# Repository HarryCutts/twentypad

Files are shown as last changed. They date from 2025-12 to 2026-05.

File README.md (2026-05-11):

# TwentyPad
TwentyPad is a simple twenty-key macro pad, that I built to learn about PCB design.

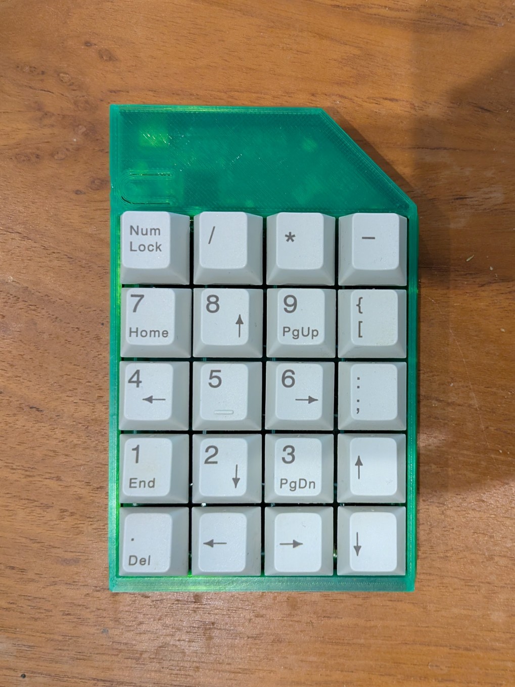
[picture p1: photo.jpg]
Photo of TwentyPad in its 3D-printed case


This repository contains the KiCAD project for PCB manufacture and assembly. The case was [designed
in Onshape][onshape-proj].

[onshape-proj]: https://cad.onshape.com/documents/e1701c21a3cb18f7b5686e27/w/70a0bcde95206762f85e44bf/e/dfee6d06467dfd7de2e80397

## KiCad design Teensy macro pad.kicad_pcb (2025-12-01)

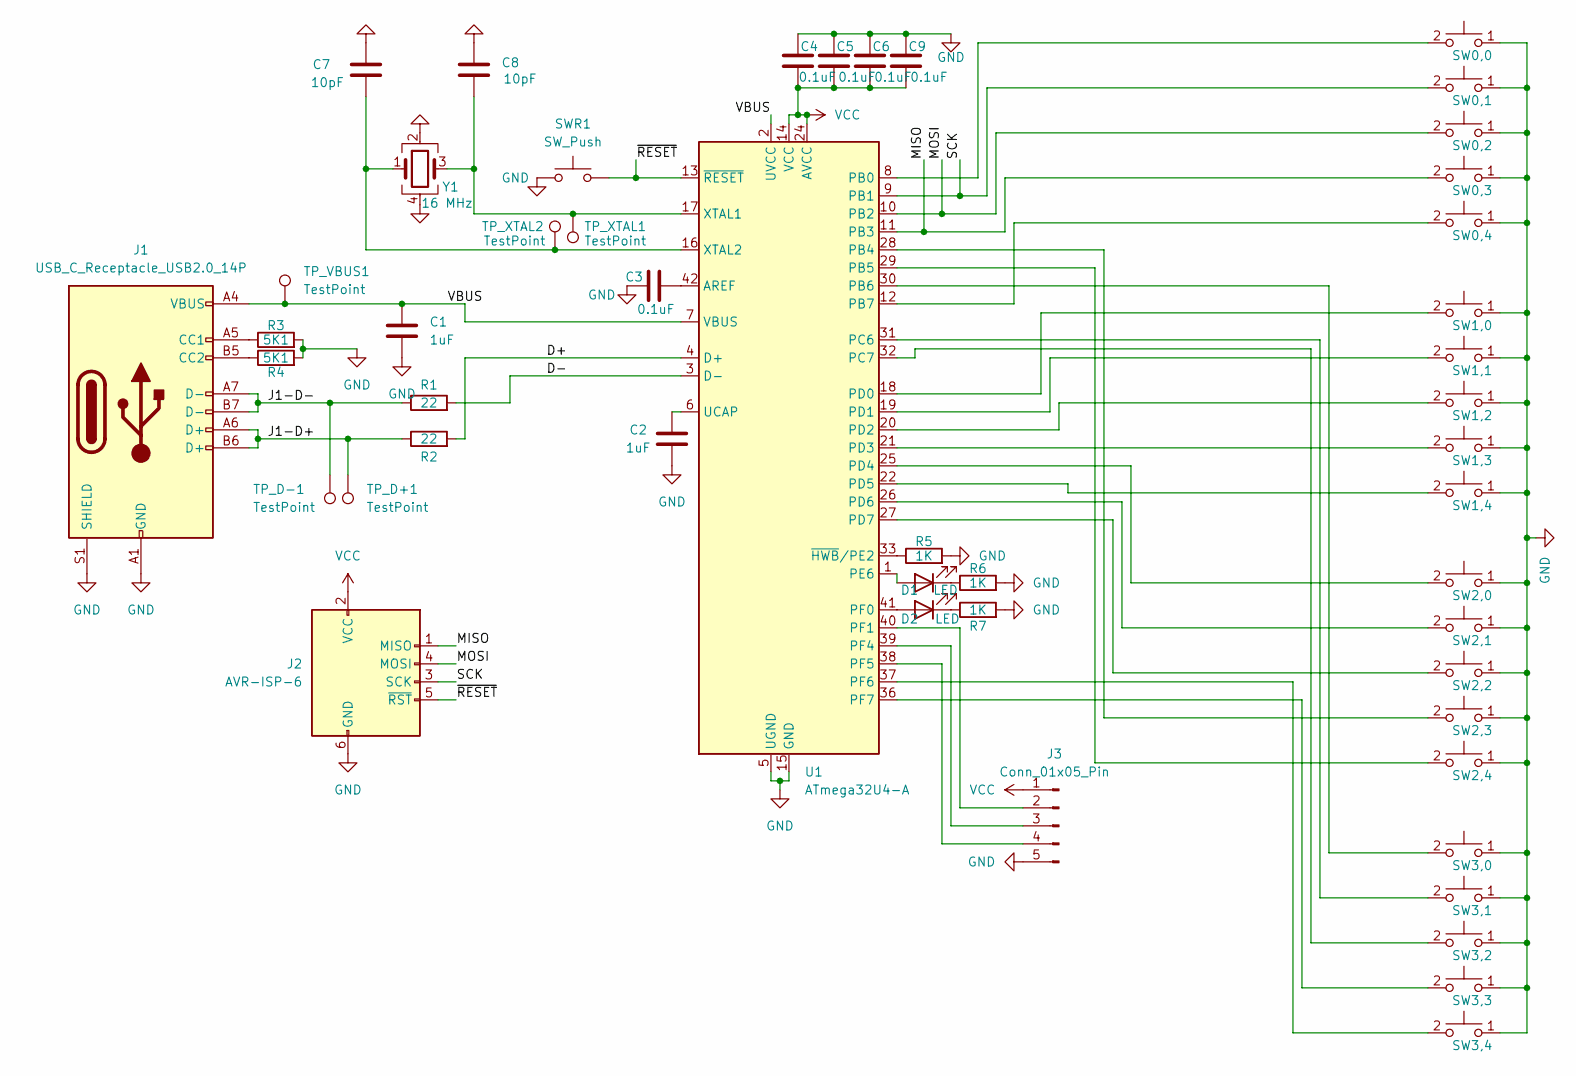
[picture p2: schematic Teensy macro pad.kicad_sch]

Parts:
C1, C2: 1uF; C_0805_2012Metric
C3, C4, C5, C6, C9: 0.1uF; C_0805_2012Metric
C7, C8: 10pF; C_0603_1608Metric
D1, D2: LED; LED_D5.0mm
J1: USB_C_Receptacle_USB2.0_14P; USB_C_Receptacle_HRO_TYPE-C-31-M-12
J2: AVR-ISP-6; IDC-Header_2x03_P2.54mm_Vertical
J3: Conn_01x05_Pin; PinHeader_1x05_P2.54mm_Vertical
R1, R2: 22; R_0805_2012Metric
R3, R4: 5K1; R_0805_2012Metric
R5, R6, R7: 1K; R_0805_2012Metric
SW0,0, SW0,1, SW0,2, SW0,3, SW0,4, SW1,0, SW1,1, SW1,2, SW1,3, SW1,4, SW2,0, SW2,1, SW2,2, SW2,3, SW2,4, SW3,0, SW3,1, SW3,2, SW3,3, SW3,4: CherryMX; SW_Cherry_MX_1.00u_PCB_with_bridge
SWR1: SW_Push; SW_Push_1P1T_XKB_TS-1187A
TP_D+1: TestPoint; TestPoint_Pad_D2.0mm
TP_D-1: TestPoint; TestPoint_Pad_D2.0mm
TP_VBUS1: TestPoint; TestPoint_Pad_D2.0mm
TP_XTAL1, TP_XTAL2: TestPoint; TestPoint_Pad_D2.0mm
U1: ATmega32U4-A; TQFP-44_10x10mm_P0.8mm
Y1: 16 MHz; Crystal_SMD_3225-4Pin_3.2x2.5mm

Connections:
/D+: R2.2, U1.4 (D+)
/D-: R1.2, U1.3 (D-)
/J1-D+: J1.A6 (D+), J1.B6 (D+), R2.1, TP_D+1.1
/J1-D-: J1.A7 (D-), J1.B7 (D-), R1.1, TP_D-1.1
/MISO: J2.1 (MISO), SW0,3.2, U1.11 (PB3)
/MOSI: J2.4 (MOSI), SW0,2.2, U1.10 (PB2)
/SCK: J2.3 (SCK), SW0,1.2, U1.9 (PB1)
/VBUS: C1.1, J1.A4 (VBUS), J1.A9 (VBUS), J1.B4 (VBUS), J1.B9 (VBUS), TP_VBUS1.1, U1.2 (UVCC), U1.7 (VBUS)
/~RESET: J2.5 (~RST), SWR1.2, U1.13 (~RESET)
GND: C1.2, C2.2, C3.1, C4.2, C5.2, C6.2, C7.1, C8.1, C9.2, J1.A1 (GND), J1.A12 (GND), J1.B1 (GND), J1.B12 (GND), J1.S1 (SHIELD), J2.6 (GND), J3.5, R3.2, R4.2, R5.2, R6.2, R7.2, SW0,0.1, SW0,1.1, SW0,2.1, SW0,3.1, SW0,4.1, SW1,0.1, SW1,1.1, SW1,2.1, SW1,3.1, SW1,4.1, SW2,0.1, SW2,1.1, SW2,2.1, SW2,3.1, SW2,4.1, SW3,0.1, SW3,1.1, SW3,2.1, SW3,3.1, SW3,4.1, SWR1.1, U1.5 (UGND), U1.15 (GND), U1.23 (GND), U1.35 (GND), U1.43 (GND), Y1.2, Y1.4
unnamed: D1.2 (A), U1.1 (PE6)
unnamed: D1.1 (K), R6.1
unnamed: D2.2 (A), U1.41 (PF0)
unnamed: D2.1 (K), R7.1
unnamed: J1.A5 (CC1), R3.1
unnamed: J1.B5 (CC2), R4.1
unnamed: J3.2, U1.40 (PF1)
unnamed: J3.3, U1.39 (PF4)
unnamed: J3.4, U1.38 (PF5)
unnamed: C3.2, U1.42 (AREF)
unnamed: SW0,0.2, U1.8 (PB0)
unnamed: SW2,3.2, U1.28 (PB4)
unnamed: SW2,4.2, U1.29 (PB5)
unnamed: SW3,0.2, U1.30 (PB6)
unnamed: SW0,4.2, U1.12 (PB7)
unnamed: SW3,1.2, U1.31 (PC6)
unnamed: SW3,2.2, U1.32 (PC7)
unnamed: SW1,0.2, U1.18 (PD0)
unnamed: SW1,1.2, U1.19 (PD1)
unnamed: SW1,2.2, U1.20 (PD2)
unnamed: SW1,3.2, U1.21 (PD3)
unnamed: SW2,0.2, U1.25 (PD4)
unnamed: SW1,4.2, U1.22 (PD5)
unnamed: SW2,1.2, U1.26 (PD6)
unnamed: SW2,2.2, U1.27 (PD7)
unnamed: SW3,4.2, U1.37 (PF6)
unnamed: SW3,3.2, U1.36 (PF7)
unnamed: C2.1, U1.6 (UCAP)
unnamed: C8.2, TP_XTAL1.1, U1.17 (XTAL1), Y1.3
unnamed: C7.2, TP_XTAL2.1, U1.16 (XTAL2), Y1.1
unnamed: R5.1, U1.33 (~HWB/PE2)
VCC: C4.1, C5.1, C6.1, C9.1, J2.2 (VCC), J3.1, U1.14 (VCC), U1.24 (AVCC), U1.34 (VCC), U1.44 (AVCC)

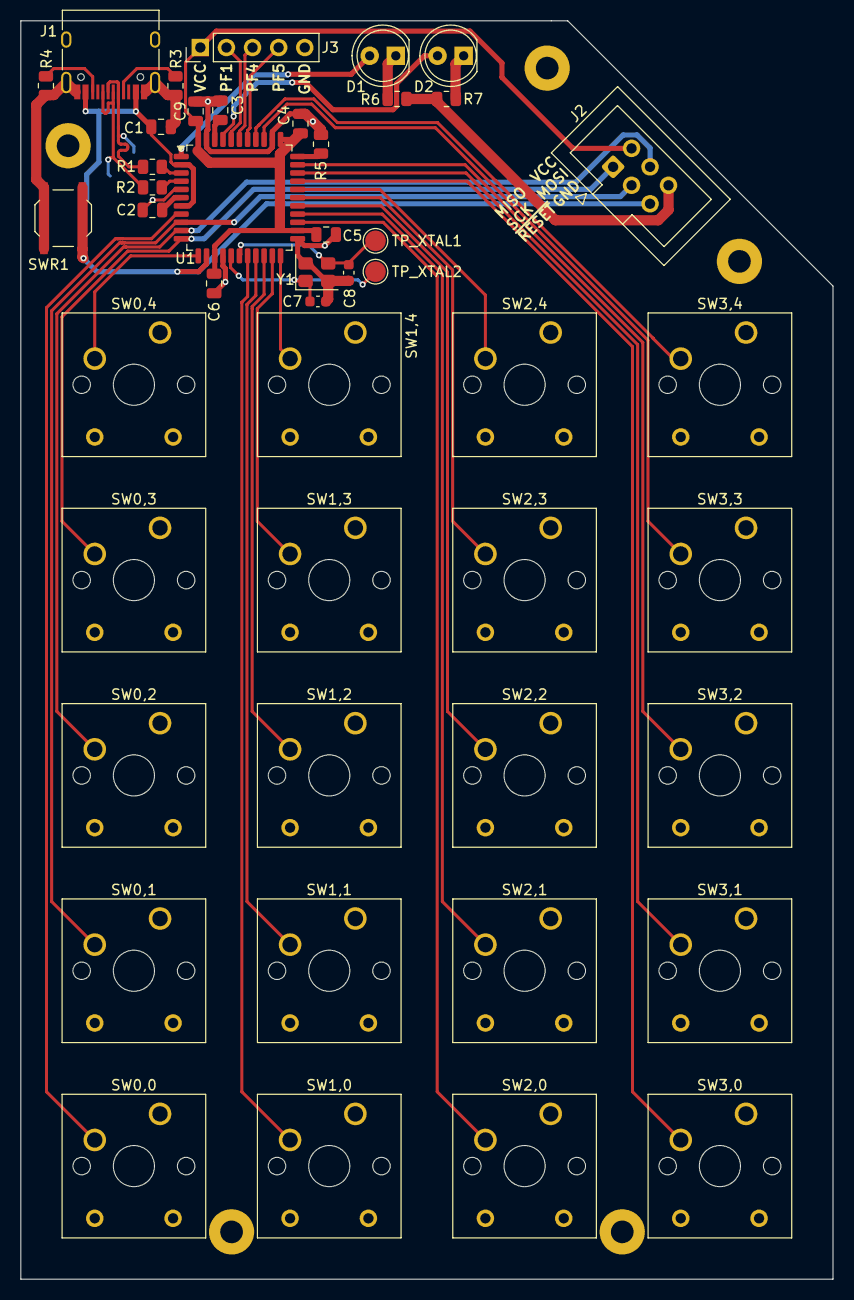
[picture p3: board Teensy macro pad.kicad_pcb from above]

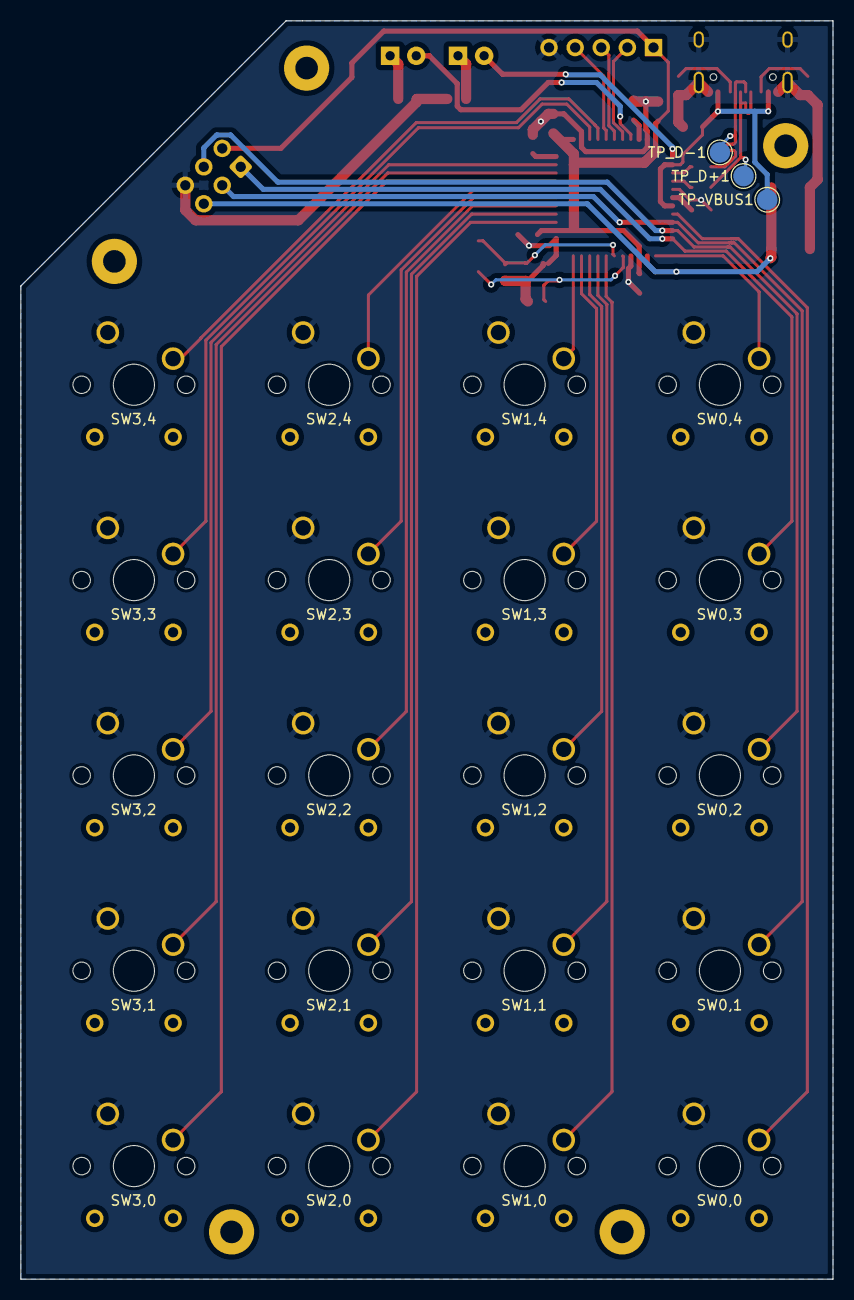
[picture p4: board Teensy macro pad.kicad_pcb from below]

Board: 2 copper layers, 79.0 x 122.4 mm, 54 parts (3 on the bottom side), 42 nets.

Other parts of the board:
HOLE1, HOLE2, HOLE3, HOLE4, HOLE5: MountingHole_2.2mm_M2_Pad

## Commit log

2025-06-28 Add partially-complete design with Teensy 2.0
    [Teensy macro pad.kicad_pcb, Teensy macro pad.kicad_sch]
2025-07-05 Switch to putting the chip on the board directly
    [Teensy macro pad.kicad_pcb, Teensy macro pad.kicad_sch]
2025-07-05 Load in JLCPCB capabilities and fix some violations
    I loaded the constraints from https://jlcpcb.com/capabilities/ into the
    board setup, then ran the DRC and fixed some of the issues (not all,
    since I need to do some re-arrangement anyway).
    [Teensy macro pad.kicad_pcb]
2025-07-06 Move decoupling capacitors to be one per VCC pin
    Pages 5 and 6 of AN2519 [0] are particularly relevant here.
    [0]: https://ww1.microchip.com/downloads/aemDocuments/documents/MCU08/ApplicationNotes/ApplicationNotes/AN2519-AVR-Microcontroller-Hardware-Design-Considerations-00002519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
    [Teensy macro pad.kicad_pcb, Teensy macro pad.kicad_sch]
2025-07-06 Add a decoupling capacitor to VCC pin 44
    This isn't on the Teensy, but AN2519 is quite clear that "For devices
    with multiple pairs of power and ground pins, it is essential that there
    is a decoupling capacitor for every pair of pins."
    [Teensy macro pad.kicad_pcb, Teensy macro pad.kicad_sch]
2025-07-14 Change and move USB-C connector footprint
    The old footprint was causing DRC errors (due to pads being too close to
    its holes). Replace it with the one Matthew recommends
    (...TYPE-C-31-M-12) and also move it so the edge of the connector
    overhangs the board edge to make it easier to put the board in a case or
    something.
    [Teensy macro pad.kicad_pcb, Teensy macro pad.kicad_sch]
2025-09-29 Fix some hole clearance errors
    [Teensy macro pad.kicad_pcb]
2025-09-29 Move some silkscreen labels
    [Teensy macro pad.kicad_pcb]
2025-09-29 Add test points for VBUS, XTAL1, and XTAL2
    [Teensy macro pad.kicad_pcb, Teensy macro pad.kicad_sch]
2025-10-04 Add holes for bridge pins on the switches
    The switches I intend to use for the project have two extra pins in the
    bottom corners, which are simply bridged together. Rather than cut them
    off, it seems like a good opportunity to try customizing a footprint, so
    create a modified footprint which adds holes for the pins. The Cherry MX
    datasheet [0] provided pin locations and recommended hole dimensions.
    [0]: https://cdn.sparkfun.com/datasheets/Components/Switches/MX%20Series.pdf
    [Teensy macro pad.kicad_pcb, Teensy macro pad.kicad_sch]
2025-10-06 Add rear silkscreen labels for switches
    [Teensy macro pad.kicad_pcb]
2025-10-13 Add mounting holes
    [Teensy macro pad.kicad_pcb]
2025-10-13 Update MCU footprint
    [Teensy macro pad.kicad_pcb]
2025-10-13 Add JLCPCB part numbers
    C7 and C8 (10pF capacitors) had to be changed to a smaller 0603
    footprint, so that I could use parts on the basic JLCPCB parts list.
    [Teensy macro pad.kicad_pcb, Teensy macro pad.kicad_sch]
2025-10-20 Add labels and improve silkscreens
    Capacitors and resistors now follow the rule that their silkscreen label
    should be in the same orientation as the component. Also added labels
    for pin headers, and a copyright notice and GitHub link to the back.
    [Teensy macro pad.kicad_pcb]
2025-10-20 Add USB test points
    [Teensy macro pad.kicad_pcb, Teensy macro pad.kicad_sch]
2025-10-27 Rename reset switch symbol
    Having a switch with reference SW1 as well as ones with SW1,0 to SW1,4
    seemed to confuse Fabrication Toolkit or JLCPCB's BOM processor.
    [Teensy macro pad.kicad_pcb, Teensy macro pad.kicad_sch]
2025-12-01 Add a 3D model for the switches
    This should make KiCAD's exported model more useful for case design.
    [Teensy macro pad.kicad_pcb]

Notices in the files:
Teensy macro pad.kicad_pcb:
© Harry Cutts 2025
